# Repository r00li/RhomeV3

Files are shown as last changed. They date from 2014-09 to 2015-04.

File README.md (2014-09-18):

Rhome V3
=========

Rhome V3 is a stand-alone ARM based room automation system. It features:

  - (Wireless) Light control
  - Window blind control
  - Local LCD based GUI
  - Wireless remote control (for now 433MHz remotes only)
  - Wifi connectivity
  - Easy to use web control interface (integrated web server)

It runs on a standard STM32F4 Cortex M4 microcontroller. This project includes all the necessary source code (EMBLOCKS PROJECT folder) and eagle board files with schematics (SCHEMATIC folder). I will also add .stl files for a 3D printed case later.

Changelog
----

0.1:

This is an alpha release and needs a lot of code cleanup. More details on how to set eveything up are comming later.

Requirements
-----------

You will need the following things to get this running:

  - A built and ready Rhome V3 PCB (or an STM32F4 discovery board with necessary components connected)
  - A sailwinch servo for each window blind that you want to control (more details are comming later)
  - A wireless 433MHz switch for each light that you want to control (I am using ones made by Intertechno, but others should work)
  - An STM32F4 Discovery board for programming (anything with STLINK should work though)
  - 5V power supply (computer USB port should work though some have trouble powering the PCB with servo motors attached)
  - A running installation of em::blocks IDE (open source, very easy to use) for compiling and uploading the project to the board

After that you just need is to connect your STLINK programmer to the programming interface on the board, select release in the em::blocks IDE and upload the code to the board. All the configuration is done through the integrated GUI.

License
----

GNU GPL v3 - see LICENSE for more details

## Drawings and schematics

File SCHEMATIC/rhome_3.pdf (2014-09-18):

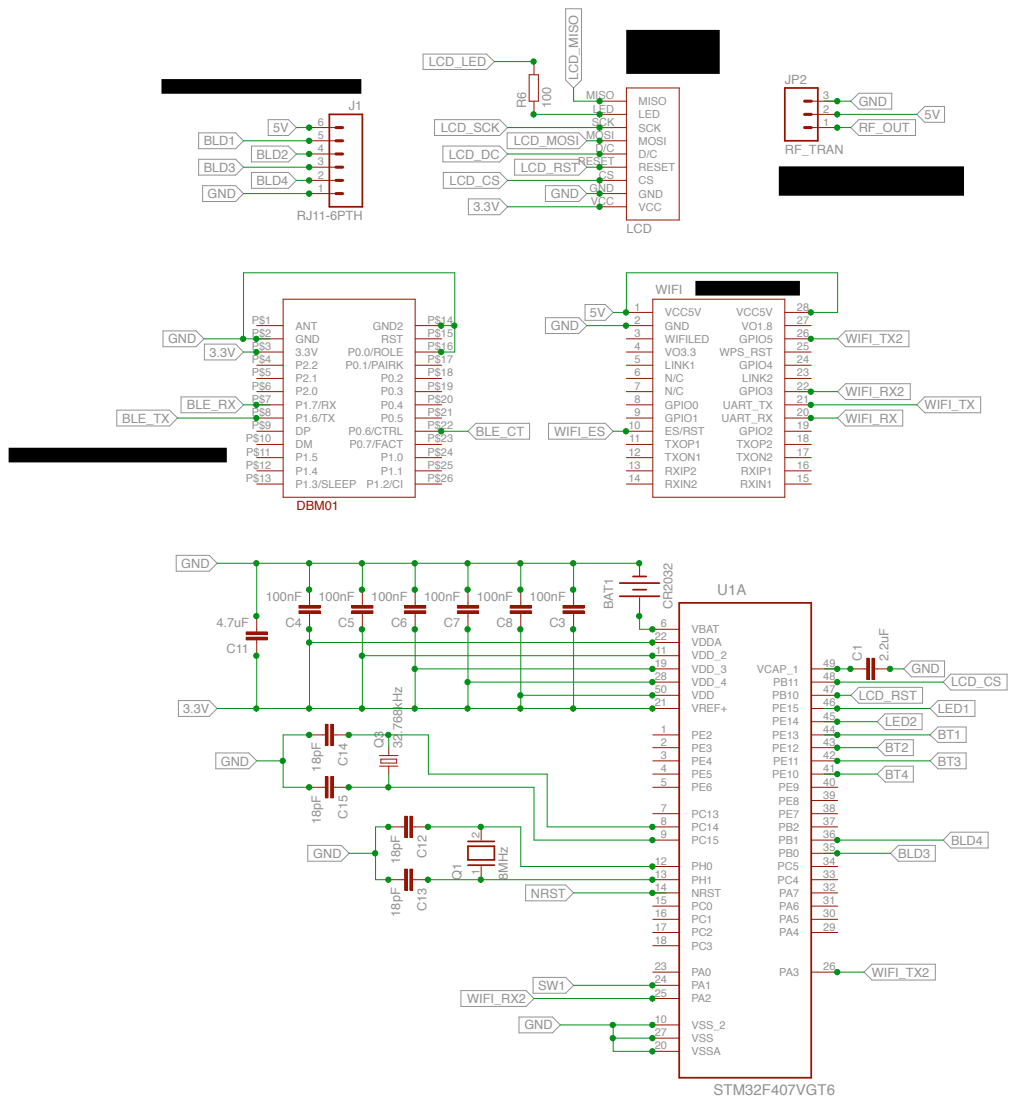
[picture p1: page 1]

VDD_2 11
VDD_3 19
VDD_4 28
VDD 50

# LCD_MISOUSB

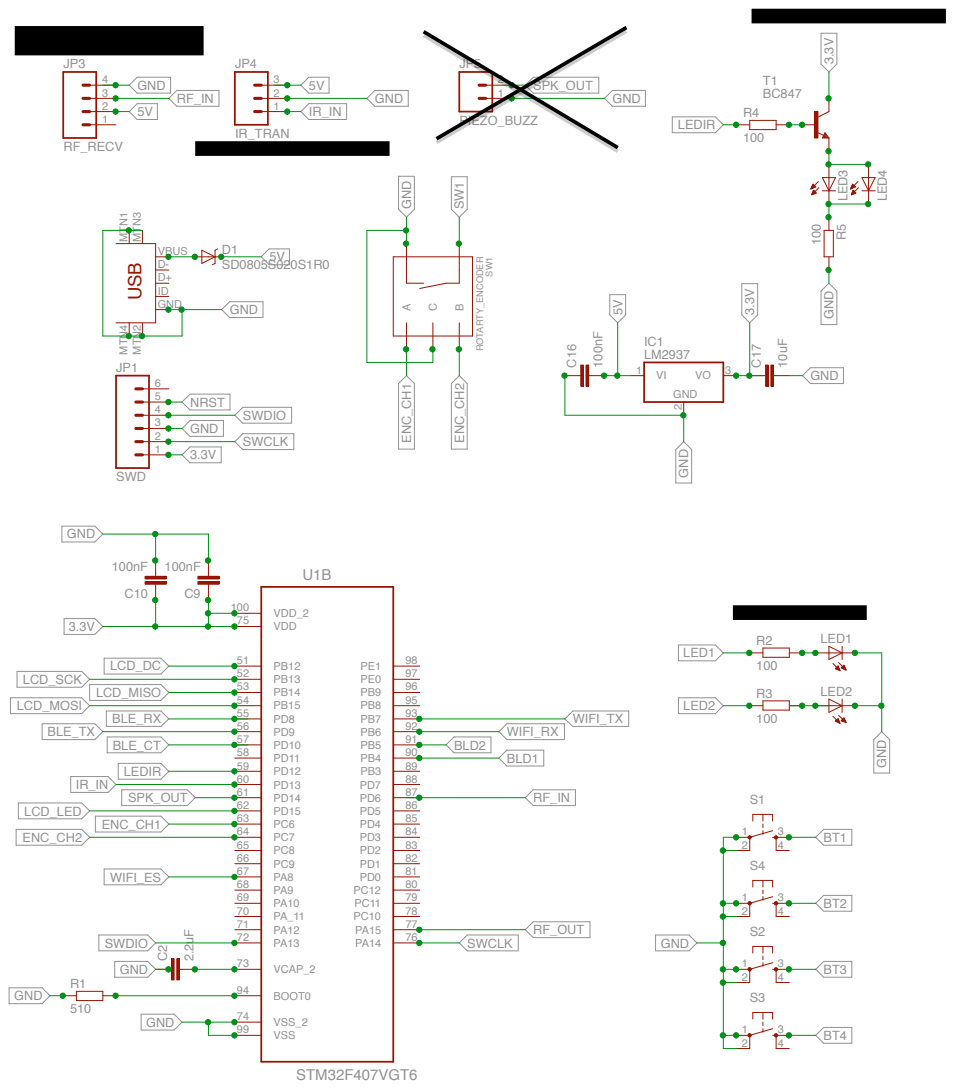
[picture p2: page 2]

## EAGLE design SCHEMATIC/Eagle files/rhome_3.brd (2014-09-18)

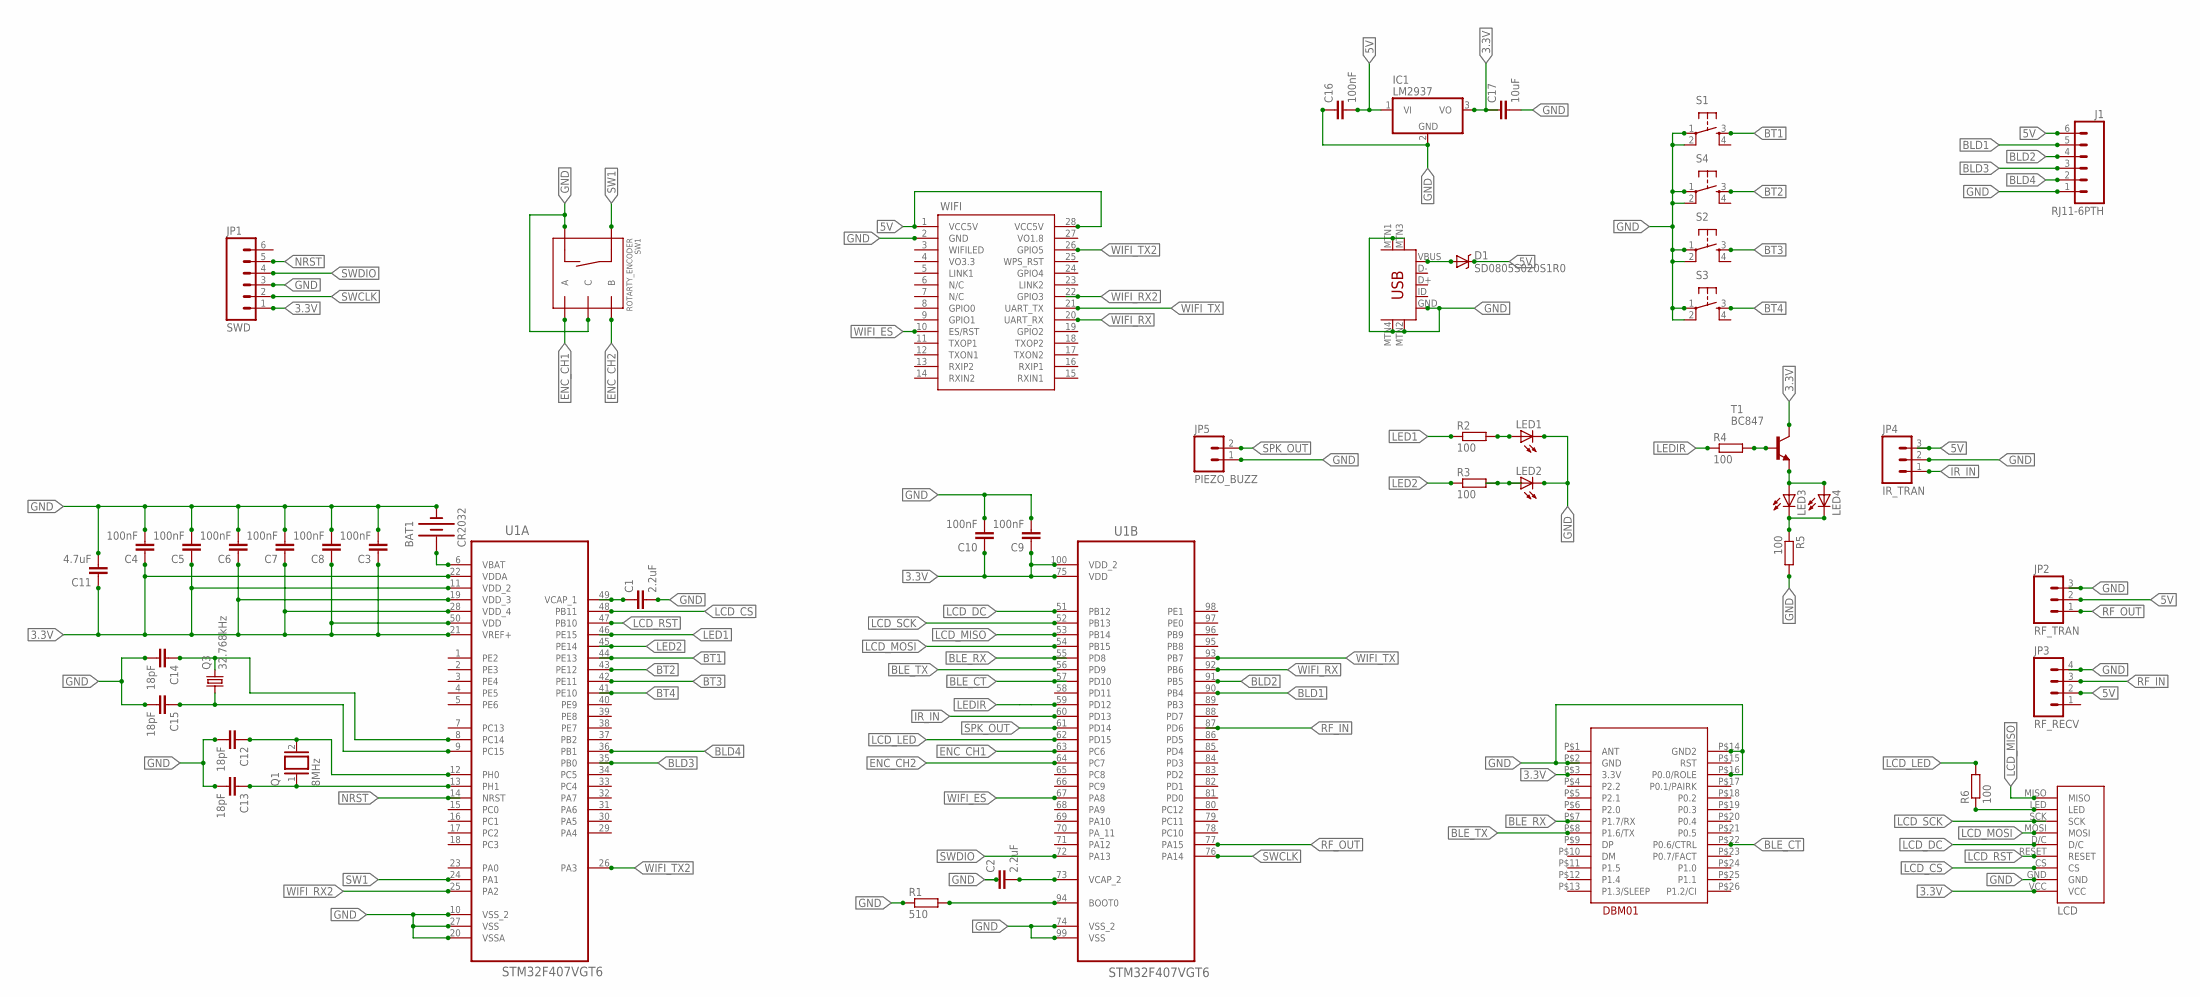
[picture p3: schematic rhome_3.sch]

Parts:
BAT1: CR2032; BATTCON_20MM
C1, C2: 2.2uF; 0805
C3, C4, C5, C6, C7, C8, C9, C10, C16: 100nF; 0805
C11: 4.7uF; 0805
C12, C13, C14, C15: 18pF; 0805
C17: 10uF; 0805
D1: SD0805S020S1R0; SOD-323
DBM01: DBM01; SMD
IC1: LM2937; TO263-3
J1: RJ11-6PTH; RJ11-6
JP1: SWD; 1X06
JP2: RF_TRAN; 1X03
JP3: RF_RECV; 1X04
JP4: IR_TRAN; 1X03
JP5: PIEZO_BUZZ; 1X02_LOCK
LCD: ILI9341_SPI_LCD; LCD
LED1, LED2, LED3, LED4: LED5MM
Q1: 8MHz; QS
Q3: 32.768kHz; MC-306
R1: 510; R0805
R2, R3, R4, R5, R6: 100; R0805
S1, S2, S3, S4: TAC_SWITCHPTH; TACTILE-PTH
SW1: ROTARTY_ENCODER; ROTARY_ENC_PLAIN
T1: BC847; SOT23
U1: STM32F407VGT6; QFP50P1600X1600X160-100N
U$1: USB-MINIB-5PIN; USB-MINIB
WIFI: HLK-RM04

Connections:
3.3V: C3.1, C4.1, C5.1, C6.1, C7.1, C8.1, C9.1, C10.1, C11.1, C17.1, DBM01.P$3 (3.3V), IC1.3 (VO), JP1.1, LCD.VCC, T1.3 (C), U1.11 (VDD_2), U1.19 (VDD_3), U1.21 (VREF+), U1.22 (VDDA), U1.28 (VDD_4), U1.50 (VDD), U1.75 (VDD), U1.100 (VDD_2)
5V: C16.2, D1.1 (C), IC1.1 (VI), J1.6, JP2.2, JP3.2, JP4.3, WIFI.1 (VCC5V), WIFI.28 (VCC5V)
BLD1: J1.5, U1.90 (PB4)
BLD2: J1.4, U1.91 (PB5)
BLD3: J1.3, U1.35 (PB0)
BLD4: J1.2, U1.36 (PB1)
BLE_CT: DBM01.P$22 (P0.6/CTRL), U1.57 (PD10)
BLE_RX: DBM01.P$7 (P1.7/RX), U1.55 (PD8)
BLE_TX: DBM01.P$8 (P1.6/TX), U1.56 (PD9)
BT1: S1.3, U1.44 (PE13)
BT2: S4.3, U1.43 (PE12)
BT3: S2.3, U1.42 (PE11)
BT4: S3.3, U1.41 (PE10)
ENC_CH1: SW1.A, U1.63 (PC6)
ENC_CH2: SW1.B, U1.64 (PC7)
GND: BAT1.2 (-), C1.2, C2.1, C3.2, C4.2, C5.2, C6.2, C7.2, C8.2, C9.2, C10.2, C11.2, C12.2, C13.2, C14.2, C15.2, C16.1, C17.2, DBM01.P$2 (GND), DBM01.P$14 (GND2), DBM01.P$16 (P0.0/ROLE), IC1.2 (GND), J1.1, JP1.3, JP2.3, JP3.4, JP4.2, JP5.1, LCD.GND, LED1.K (C), LED2.K (C), R1.1, R5.2, S1.1, S1.2, S2.1, S2.2, S3.1, S3.2, S4.1, S4.2, SW1.C, SW1.SW-, U1.10 (VSS_2), U1.20 (VSSA), U1.27 (VSS), U1.74 (VSS_2), U1.99 (VSS), U$1.GND, U$1.MTN1 (MTN2), U$1.MTN2 (MTN3), U$1.MTN3 (MTN1), U$1.MTN4, WIFI.2 (GND)
IR_IN: JP4.1, U1.60 (PD13)
LCD_CS: LCD.CS, U1.48 (PB11)
LCD_DC: LCD.D/C, U1.51 (PB12)
LCD_LED: R6.2, U1.62 (PD15)
LCD_MISO: LCD.MISO, U1.53 (PB14)
LCD_MOSI: LCD.MOSI, U1.54 (PB15)
LCD_RST: LCD.RESET, U1.47 (PB10)
LCD_SCK: LCD.SCK, U1.52 (PB13)
LED1: R2.1, U1.46 (PE15)
LED2: R3.1, U1.45 (PE14)
LEDIR: R4.1, U1.59 (PD12)
unnamed: C2.2, U1.73 (VCAP_2)
unnamed: C1.1, U1.49 (VCAP_1)
unnamed: C14.1, Q3.4 (2), U1.8 (PC14)
unnamed: C13.1, Q1.1, U1.13 (PH1)
unnamed: C12.1, Q1.2, U1.12 (PH0)
unnamed: C15.1, Q3.1, U1.9 (PC15)
unnamed: D1.2 (A), U$1.VBUS
unnamed: BAT1.1 (+), U1.6 (VBAT)
unnamed: LED1.A, R2.2
unnamed: LED2.A, R3.2
unnamed: R4.2, T1.1 (B)
unnamed: LED3.A, LED4.A, T1.2 (E)
unnamed: R1.2, U1.94 (BOOT0)
unnamed: LED3.K (C), LED4.K (C), R5.1
unnamed: LCD.LED, R6.1
NRST: JP1.5, U1.14 (NRST)
RF_IN: JP3.3, U1.87 (PD6)
RF_OUT: JP2.1, U1.77 (PA15)
SPK_OUT: JP5.2, U1.61 (PD14)
SW1: SW1.SW+, U1.24 (PA1)
SWCLK: JP1.2, U1.76 (PA14)
SWDIO: JP1.4, U1.72 (PA13)
WIFI_ES: U1.67 (PA8), WIFI.10 (ES/RST)
WIFI_RX: U1.92 (PB6), WIFI.20 (UART_RX)
WIFI_RX2: U1.25 (PA2), WIFI.22 (GPIO3)
WIFI_TX: U1.93 (PB7), WIFI.21 (UART_TX)
WIFI_TX2: U1.26 (PA3), WIFI.26 (GPIO5)

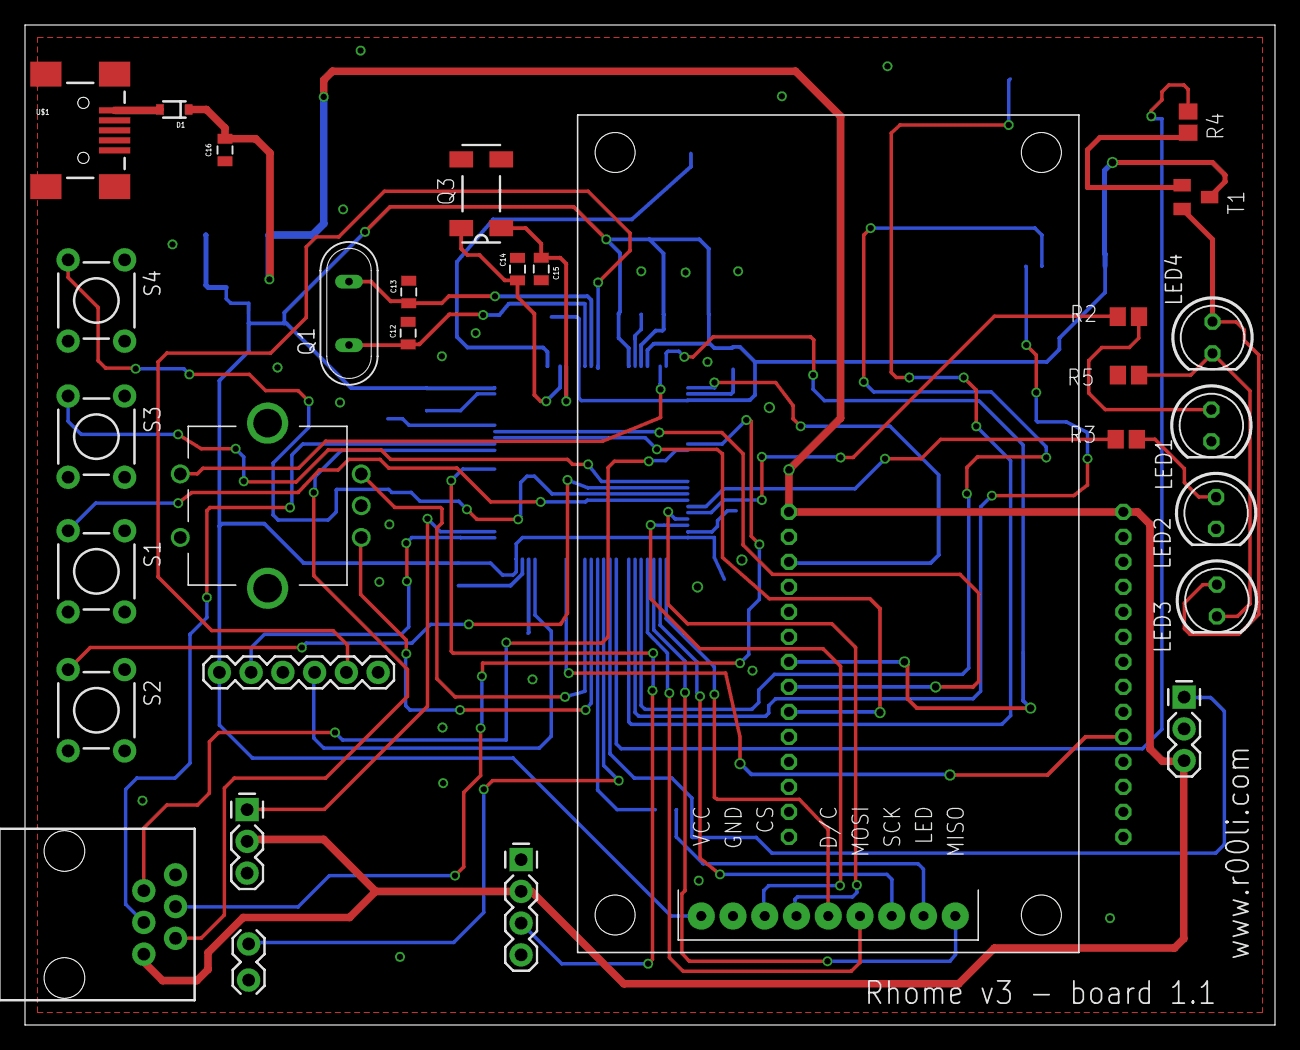
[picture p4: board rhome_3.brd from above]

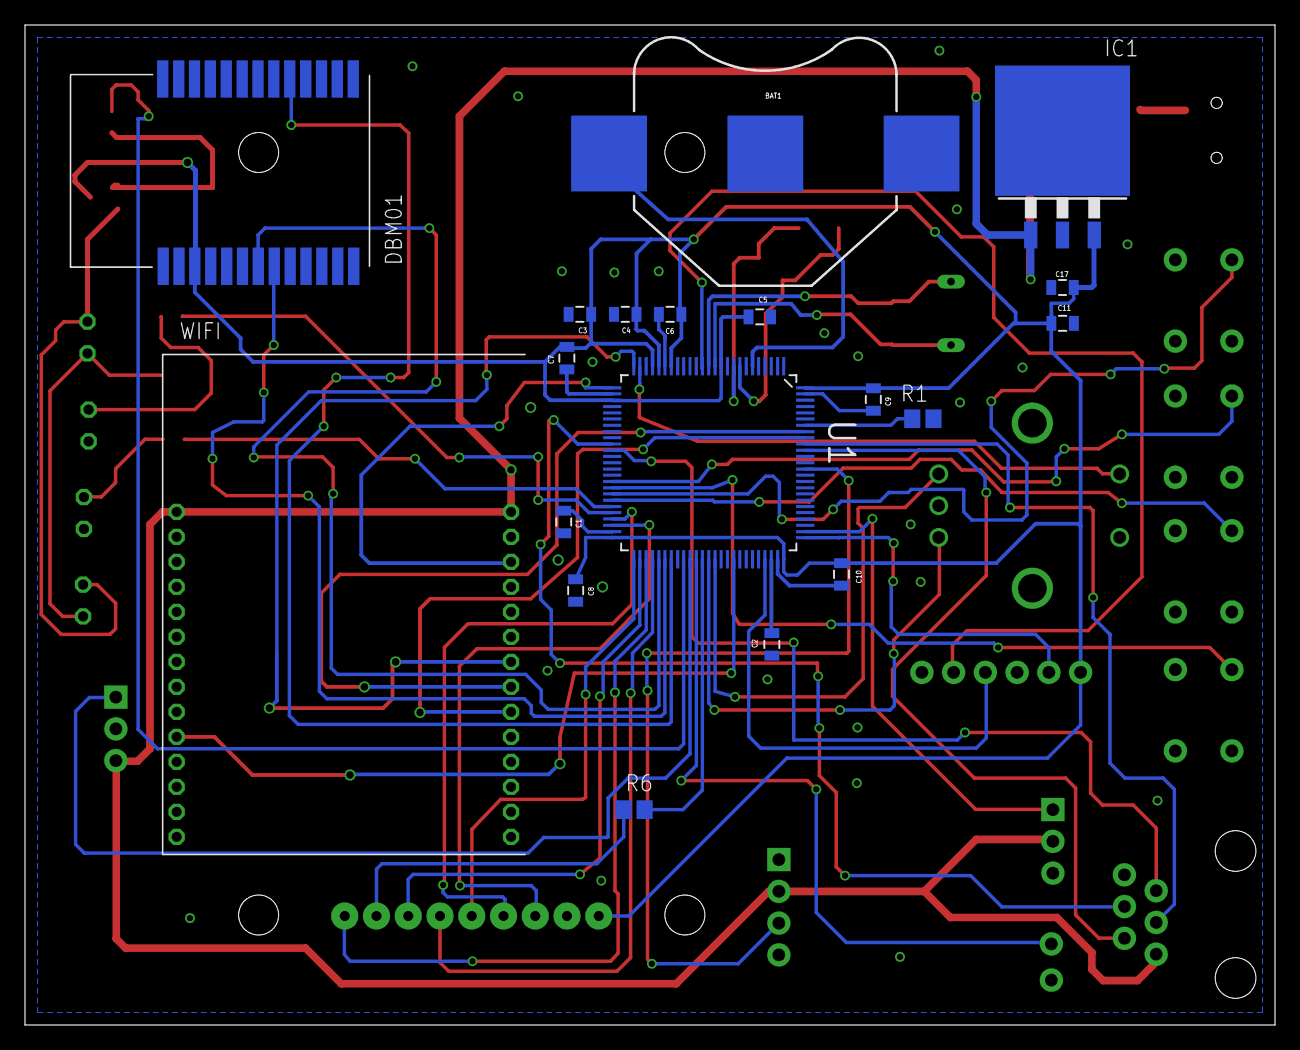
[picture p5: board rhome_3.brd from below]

Board: 2 copper layers, 100.0 x 80.0 mm, 49 parts (19 on the bottom side), 54 nets.

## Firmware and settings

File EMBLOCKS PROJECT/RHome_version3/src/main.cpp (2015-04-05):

/*
**
**                           Main.cpp
**
**
**********************************************************************/
/*
   Author:                 Andrej Rolih
                           www.r00li.com
   Version:                0.1
   License:                GNU GPL v3
                           See attached LICENSE file for details
                           External library files do not include such header and
                           are released under GPL v3 or their specific license.
                           Check those files for more details.

**********************************************************************/

#include "stm32f4xx_conf.h"
#include "stm32f4xx_exti.h"
#include "stm32f4xx_gpio.h"
#include "stm32f4xx_rcc.h"
#include "stm32f4xx_usart.h"
#include "misc.h"
#include "stm32f4xx_syscfg.h"
#include "stm32f4xx_rtc.h"
#include "stm32f4xx_pwr.h"
#include "stm32f4xx_flash.h"


#include "tm_stm32f4_ili9341.h"
#include "tm_stm32f4_fonts.h"

#include "FreeRTOS.h"
#include "task.h"
#include "semphr.h"

#include <stdio.h>
#include <string>
#include <sstream>
#include <stdlib.h>
#include <functional>

#include "Lighting.h"
#include "Menu.h"
#include "Blinds.h"
#include "RemoteTransmitter.h"
#include "RemoteReceiver.h"
#include "TempSensor.h"
#include "Remote.h"

#include "essentials.h"

//
// Redefinition of operators new and delete so that
// dynamic memory allocation can work with Free RTOS
//
void *operator new(size_t size)
{
    void *p;

    if(uxTaskGetNumberOfTasks())
        p=pvPortMalloc(size);
    else
        p=malloc(size);

    return p;
}

void operator delete(void *p)
{
    if(uxTaskGetNumberOfTasks())
        vPortFree( p );
    else
        free( p );

    p = NULL;
}

//
// Functions declarations for some of the functions
//
void Delay(__IO uint32_t nCount);
void vApplicationStackOverflowHook( xTaskHandle pxTask, signed char *pcTaskName );
void vApplicationMallocFailedHook(void);
void vTask1Function (void *pvParameters);
void vTask2Function (void *pvParameters);
void menuCheckerTask(void *pvParameters);
void displayInfoScreen();
void remoteEvent(uint32_t event_code);

//
// Settings for maximum number of automation units
// Also definitions for vectors where we store this data
//
#define kMAX_LIGHTS 5
#define kMAX_BLINDS 4
#define kMAX_BUTTONS 50
std::vector<Light *> lights;
std::vector<Blind *> blinds;
std::vector<RemoteButton *> remoteButtons;

//
// Menu variables (menu stack, currently drawn menu options, ...)
//
std::vector<MenuOption *> mainMenuOptions;
std::vector<std::vector<MenuOption *>> menuStack;
std::vector<MenuOption *> pressedMenuOptionsStack;

//
// Temperature sensing variables
//
InternalTempSensor tempSensor;
uint8_t tempAdjust = 0;

//
// Wifi connection 1 buffer
//
const int eth1_buff_size = 800;
volatile char eth1_buff[eth1_buff_size];
volatile int eth1_buff_indicator = 0;
volatile uint8_t eth1_busy = 0;

//
// Wifi connection 2 buffer
//
const int eth2_buff_size = 400;
volatile char eth2_buff[eth2_buff_size];
volatile int eth2_buff_indicator = 0;
volatile uint8_t eth2_busy = 0;

//
// Ethernet response buffer
//
char eth_send_buff[6000];
volatile unsigned int eth_send_pointer = 0;

//
// Some global buffers for use across the code
//
int globalIntBuffer[10];
char text_buffer[70];
char mini_text_buffer1[35];
char mini_text_buffer2[35];
char mini_text_buffer3[35];

//
// Alphabet definition (for on-screen keyboard)
//
const char alphabet[][2] = {"a","b","c","d","e","f","g","h","i","j","k","l","m","n","o","p","q","r","s","t","u","v","w","x","y","z", " ","A","B","C","D","E","F","G","H","I","J","K","L","M","N","O","P","Q","R","S","T","U","V","W","X","Y","Z", "0", "1", "2", "3", "4", "5", "6", "7", "8", "9", "_", "-", ".", ",", "+", "(", ")"};
#define kALPHABET_SIZE 70

//
// HLK-RM04 Wifi encryption options and their pretty versions
//
const char wifiEncryptionTypes[][11] = {"None", "WEP open", "WEP", "WPA TKIP", "WPA AES", "WPA2 TKIP", "WPA2 AES", "WPA/2 TKIP", "WPA/2 AES"};
const char wifiEcnryptionCommands[][13] = {"none", "wep_open", "wep", "wpa_tkip", "wpa_aes", "wpa2_tkip", "wpa2_aes", "wpawpa2_tkip", "wpawpa2_aes"};
#define kWifiEncryptionTypes 9

//
// Default web server settings
//
char web_user[15] = "user";
char web_pass[15] = "user";
int webPort = 8080;

//
// Variables for blue status LED
//
int blueLedOnTime = 0;
bool blueLedOn = false;

//
// Delayed actions variables
// Automatic blind open/close, delay light-off
//
int delayedActionTime = 0;
bool delayLightOff = false;
bool delayBlindOpen = false;
bool delayBlindClose = false;

//
// Variables for setting the autoblind timer
// (autoblind is disabled by default)
//
uint8_t automaticBlindOpenHour = 0;
uint8_t automaticBlindOpenMinute = 0;
uint8_t automaticBlindCloseHour = 0;
uint8_t automaticBlindCloseMinute = 0;
uint8_t automaticBlindOpenPosition = 0;
uint8_t automaticBlindClosePosition = 0;
bool autoOpenBlindEnabled = false;
bool autoCloseBlindEnabled = false;

//
// Flash definitions
//
const uint8_t flash_data[] __attribute__ ((section(".eeprom"), used)) = {};
uint8_t flash_status;
uint8_t empty_check;


//
// Interrupt handlers
// Using extern "C" because interrupt handlers can't be inside of C++ code
//
extern "C"
{
    void USART1_IRQHandler(void)
    {
        //
        // Wifi connection 1 handler (server)
        //
        if(USART_GetITStatus(USART1, USART_IT_RXNE) != RESET)
        {
            if (eth1_buff_indicator >= eth1_buff_size || eth1_busy)
            {
                return;
            }

            eth1_buff[eth1_buff_indicator] = USART_ReceiveData(USART1);
            eth1_buff_indicator++;
        }
    }

    void USART2_IRQHandler(void)
    {
        //
        // Wifi connection 2 handler (client)
        //
        if(USART_GetITStatus(USART2, USART_IT_RXNE) != RESET)
        {
            if (eth2_buff_indicator >= eth2_buff_size || eth2_busy)
            {
                return;
            }

            eth2_buff[eth2_buff_indicator] = USART_ReceiveData(USART2);
            eth2_buff_indicator++;
        }
    }

    void EXTI1_IRQHandler(void)
    {
        //
        // Rotary encoder integrated button handler
        //
        if (EXTI_GetITStatus(EXTI_Line1))
        {
            Menu::enterPressed = true;
            Menu::lastInteractionTime = millis();
            delay(10);
        }

        EXTI_ClearITPendingBit(EXTI_Line1);
    }

    void EXTI9_5_IRQHandler(void)
    {
        //
        // RF-receiver handler
        //
        if (EXTI_GetITStatus(EXTI_Line6) != RESET)
        {
            taskENTER_CRITICAL();
            //taskDISABLE_INTERRUPTS();
            RemoteReceiver::interruptHandler();
            EXTI_ClearITPendingBit(EXTI_Line6);
            taskEXIT_CRITICAL();
            //taskENABLE_INTERRUPTS();
        }
    }

    void EXTI15_10_IRQHandler(void)
    {
        //
        // User buttons handler
        //
        if (EXTI_GetITStatus(EXTI_Line13) != RESET)
        {
            remoteEvent(1);
            EXTI_ClearITPendingBit(EXTI_Line13);
        }

        if (EXTI_GetITStatus(EXTI_Line12) != RESET)
        {
            remoteEvent(2);
            EXTI_ClearITPendingBit(EXTI_Line12);
        }

        if (EXTI_GetITStatus(EXTI_Line11) != RESET)
        {
            remoteEvent(3);
            EXTI_ClearITPendingBit(EXTI_Line11);
        }

        if (EXTI_GetITStatus(EXTI_Line10) != RESET)
        {
            remoteEvent(4);
            EXTI_ClearITPendingBit(EXTI_Line10);
        }
    }

    void RTC_Alarm_IRQHandler()
    {
        //
        // RTC alarm handler
        // Used for autoblind
        //
        if(RTC_GetITStatus(RTC_IT_ALRA) != RESET)
        {
            if (autoOpenBlindEnabled)
                delayBlindOpen = true;
            RTC_ClearITPendingBit(RTC_IT_ALRA);
            EXTI_ClearITPendingBit(EXTI_Line17);
        }

        if(RTC_GetITStatus(RTC_IT_ALRB) != RESET)
        {
            if (autoCloseBlindEnabled)
                delayBlindClose = true;
            RTC_ClearITPendingBit(RTC_IT_ALRB);
            EXTI_ClearITPendingBit(EXTI_Line17);
        }
    }

    void HardFault_Handler()
    {
        NVIC_SystemReset();
    }
}


// ------------------------------------------------------------------------------------------------------------------------------------------------------
// FLASH FUNCTIONS
// ------------------------------------------------------------------------------------------------------------------------------------------------------

void loadFromFlash()
{
    //
    // Function loads settings from internal flash
    //

    if (flash_data[0])
    {
        empty_check = 1;
        return;
    }
    else
    {
        uint8_t* address = (uint8_t *) &flash_data[0];
        address += 4;

        //restore lights
        for (int i = 0 ; i < kMAX_LIGHTS; i++)
        {
            unsigned char *data1 = address;
            address += 4;

            uint8_t light_present = data1[0];
            uint8_t light_type = data1[1];
            uint8_t device = data1[3];

            char name[12];
            for (int j=0; j < 12; j++)
            {
                name[j] = *address;
                address++;
            }
            name[11] = '\0';

            uint32_t bt_code = *((uint32_t *)address);
            address += 4;

            uint32_t system_code = *((uint32_t *)address);
            address += 4;

            //additional unused bits
            address += 8;

            if (light_present == 0)
            {
                Light *lght = new Light;
                lght->setName(name);
                lght->btCode = bt_code;

                if (light_type == RF_KAKU)
                    lght->setTypeKaku(device, (unsigned short) system_code);

                lght->onOff(false);

                lights.push_back(lght);
            }
        }

        //restore blinds
        for (int i = 0 ; i < kMAX_BLINDS; i++)
        {
            unsigned char *data1 = address;
            address += 4;

            uint8_t blind_present = data1[0];
            uint8_t blind_channel = data1[1];
            uint8_t blind_type = data1[2];
            //uint8_t device = data1[3];

            uint32_t bt_code = *((uint32_t *)address);
            address += 4;

            uint32_t min_pos = *((uint32_t *)address);
            address += 4;

            uint32_t mid_pos = *((uint32_t *)address);
            address += 4;

            uint32_t max_pos = *((uint32_t *)address);
            address += 4;

            uint32_t step = *((uint32_t *)address);
            address += 4;

            char name[12];
            for (int j=0; j < 12; j++)
            {
                name[j] = *address;
                address++;
            }
            name[11] = '\0';

            //additional unused bits
            address += 8;

            if (blind_present == 0)
            {
                Blind *bld = new Blind;
                bld->setName(name);
                bld->btCode = bt_code;
                bld->setBounds(min_pos, mid_pos, max_pos);
                bld->step = step;
                bld->setType((BlindType) blind_type);
                bld->setChannel((BlindChannel) blind_channel);

                bld->enableOutput(true);
                bld->setPosition(mid_pos);
                delay(1000);
                bld->enableOutput(false);

                blinds.push_back(bld);
            }
        }

        //restore remote/buttons
        for (int i = 0 ; i < kMAX_BUTTONS; i++)
        {
            unsigned char *data1 = address;
            address += 4;

            uint8_t button_present = data1[0];
            uint8_t event_type = data1[1];

            uint32_t buttonCode = *((uint32_t *)address);
            address += 4;

            uint32_t eventHash = *((uint32_t *)address);
            address += 4;

            if (button_present == 0)
            {
                RemoteButton* btn = new RemoteButton();
                btn->eventHash = eventHash;
                btn->remoteButton = buttonCode;
                btn->eventType = (RemoteEventType) event_type;

                remoteButtons.push_back(btn);
            }
        }

        //restore web server settings
        {
            unsigned char *data1 = address;
            address += 4;

            uint8_t settingsSaved = data1[0];

            uint32_t port = *((uint32_t *)address);
            address += 4;

            char user[16];
            for (int j=0; j < 16; j++)
            {
                user[j] = *address;
                address++;
            }
            user[14] = '\0';

            char pass[16];
            for (int j=0; j < 16; j++)
            {
                pass[j] = *address;
                address++;
            }
            pass[14] = '\0';

            if (settingsSaved == 0)
            {
                webPort = port;
                strncpy(web_user, user, 15);
                strncpy(web_pass, pass, 15);
            }
        }

        //restore auto blind settings
        {
            unsigned char *data1 = address;
            address += 4;

            autoOpenBlindEnabled = data1[0];
            automaticBlindOpenHour = data1[1];
            automaticBlindOpenMinute = data1[2];
            automaticBlindOpenPosition = data1[3];

            unsigned char *data2 = address;
            address += 4;

            autoCloseBlindEnabled = data2[0];
            automaticBlindCloseHour = data2[1];
            automaticBlindCloseMinute = data2[2];
            automaticBlindClosePosition = data2[3];
        }

        //restore temp adjustment factor
        {
            unsigned char *data1 = address;
            address += 4;

            if (data1[0] == 0)
            {
                tempAdjust = data1[1];
            }
        }
    }
}
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
int main(void)
{
    //
    // Main function
    // Handles basic setup and initialization
    //

    init_essentials_time();
    GPIO_LED_init();

    TM_ILI9341_Init();
    TM_ILI9341_Rotate(TM_ILI9341_Orientation_Landscape_1);

    TM_ILI9341_Puts(10, 10, "Starting...", &TM_Font_11x18, ILI9341_COLOR_BLACK, ILI9341_COLOR_WHITE);

    LCD_backlight_init();

    initRTC();

    //menuStack.reserve(3);
    //mainMenuOptions.reserve(12);
    //pressedMenuOptionsStack.reserve(6);

    blinds.reserve(4);
    lights.reserve(5);
    remoteButtons.reserve(50);

    loadFromFlash();

    setAutoBlinds();

    RemoteButton::shouldRunActions = true;

    RemoteReceiver::init(0,remoteEventRF);

    Blind::initLocalBlinds();

    Menu::initInputMethod();

    tempSensor.initTempSensor();
    tempSensor.calibration = tempAdjust;

    Menu::clearMenu();
    Menu::clearTitle();
    Menu::clearRightMenu();

    MenuOption* op1 = new MenuOption(13, 15, "Info", ILI9341_COLOR_WHITE, ILI9341_COLOR_BLACK);
    op1->setOnClickListener(displayInfoScreen);
    op1->setSelected(true);
    op1->doOnClick();

    MenuOption* op2 = new MenuOption(30, 45, "Lights", ILI9341_COLOR_WHITE, ILI9341_COLOR_BLACK);
    op2->setOnClickListener(displayLightMenu);

    MenuOption* op3 = new MenuOption(38, 75, "Blinds", ILI9341_COLOR_WHITE, ILI9341_COLOR_BLACK);
    op3->setOnClickListener(displayBlindMenu);

    MenuOption* op4 = new MenuOption(42, 105, "Actions", ILI9341_COLOR_WHITE, ILI9341_COLOR_BLACK);
    op4->setOnClickListener(displayActionMenu);

    MenuOption* op5 = new MenuOption(38, 135, "Settings", ILI9341_COLOR_WHITE, ILI9341_COLOR_BLACK);
    op5->setOnClickListener(displaySettingsMenu);

    mainMenuOptions.push_back(op1);
    mainMenuOptions.push_back(op2);
    mainMenuOptions.push_back(op3);
    mainMenuOptions.push_back(op4);
    mainMenuOptions.push_back(op5);

    initWifiES();
    init_USART1();
    init_USART2();


    //
    // Create all Free RTOS tasks
    //
    xTaskCreate(
        vTask1Function,                   /*Pinter to the function that implements task*/
        ( const signed char * ) "Task1",  /* Task name - for debugging only*/
        200,         /* Stack depth in words */
        ( void* ) NULL,                   /* Pointer to tasks arguments (parameter) */
        tskIDLE_PRIORITY + 1UL,           /* Task priority*/
        NULL                              /* Task handle */
    );

    xTaskCreate(
        vTask2Function,                   /* Pointer to the function that implements task*/
        ( const signed char * ) "Task2",  /* Task name - for debugging only*/
        200,         /* Stack depth in words */
        ( void* ) NULL,                   /* Pointer to tasks arguments (parameter) */
        tskIDLE_PRIORITY + 1UL,           /* Task priority*/
        NULL                              /* Task handle */
    );

    xTaskCreate(
        task3,                   /* Pointer to the function that implements task*/
        ( const signed char * ) "Task3",  /* Task name - for debugging only*/
        200,         /* Stack depth in words */
        ( void* ) NULL,                   /* Pointer to tasks arguments (parameter) */
        tskIDLE_PRIORITY + 1UL,           /* Task priority*/
        NULL                              /* Task handle */
    );

    xTaskCreate(
        menuCheckerTask,                   /* Pointer to the function that implements task*/
        ( const signed char * ) "Task4",  /* Task name - for debugging only*/
        600,         /* Stack depth in words */
        ( void* ) NULL,                   /* Pointer to tasks arguments (parameter) */
        tskIDLE_PRIORITY + 1UL,           /* Task priority*/
        NULL                              /* Task handle */
    );

    // Start task scheduler
    vTaskStartScheduler();

    while(1)
    {
    }
}

/**
  * @brief  Delay Function.
  * @param  nCount:specifies the Delay time length.
  * @retval None
  */
void Delay(__IO uint32_t nCount)
{
    while(nCount--)
    {
    }
}

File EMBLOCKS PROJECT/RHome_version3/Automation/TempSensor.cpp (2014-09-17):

/*
**
**                           TempSensor.cpp
**
**
**********************************************************************/
/*
   Author:                 Andrej Rolih
                           www.r00li.com
   Version:                0.1
   License:                GNU GPL v3
                           See attached LICENSE file for details
                           External library files do not include such header and
                           are released under GPL v3 or their specific license.
                           Check those files for more details.

**********************************************************************/

#include "TempSensor.h"

#include "FreeRTOS.h"
#include "task.h"

void InternalTempSensor::initTempSensor()
{
    temp = 0;
    calibration = 0;

    ADC_DeInit();

    ADC_InitTypeDef ADC_InitStruct;
    ADC_CommonInitTypeDef ADC_CommonInitStruct;

    RCC_APB2PeriphClockCmd(RCC_APB2Periph_ADC1, ENABLE);

    ADC_CommonInitStruct.ADC_Mode = ADC_Mode_Independent;
    ADC_CommonInitStruct.ADC_Prescaler = ADC_Prescaler_Div8;
    ADC_CommonInitStruct.ADC_DMAAccessMode = ADC_DMAAccessMode_Disabled;
    ADC_CommonInitStruct.ADC_TwoSamplingDelay = ADC_TwoSamplingDelay_5Cycles;
    ADC_CommonInit(&ADC_CommonInitStruct);

    ADC_InitStruct.ADC_Resolution = ADC_Resolution_12b;
    ADC_InitStruct.ADC_ScanConvMode = DISABLE;
    ADC_InitStruct.ADC_ContinuousConvMode = ENABLE;
    ADC_InitStruct.ADC_ExternalTrigConvEdge = ADC_ExternalTrigConvEdge_None;
    ADC_InitStruct.ADC_ExternalTrigConv = ADC_ExternalTrigConv_T1_CC1;
    ADC_InitStruct.ADC_DataAlign = ADC_DataAlign_Right;
    ADC_InitStruct.ADC_NbrOfConversion = 1;
    ADC_Init(ADC1, &ADC_InitStruct);

    ADC_RegularChannelConfig(ADC1, ADC_Channel_TempSensor, 1, ADC_SampleTime_144Cycles);
    ADC_TempSensorVrefintCmd(ENABLE);
    ADC_Cmd(ADC1, ENABLE);
}

void InternalTempSensor::measureTemp(bool calibrate)
{
    // ADC Conversion to read temperature sensor
    // Temperature (in °C) = ((Vsense – V25) / Avg_Slope) + 25
    // Vense = Voltage Reading From Temperature Sensor
    // V25 = Voltage at 25°C, for STM32F407 = 0.76V
    // Avg_Slope = 2.5mV/°C
    // This data can be found in the STM32F407VF Data Sheet


    taskENTER_CRITICAL();
    ADC_SoftwareStartConv(ADC1); //Start the conversion
    while (ADC_GetFlagStatus(ADC1, ADC_FLAG_EOC) == RESET) {} ; //Processing the conversion

    temp = ADC_GetConversionValue(ADC1); //Return the converted data
    temp *= 3300;
    temp /= 0xfff; //Reading in mV
    temp /= 1000.0; //Reading in Volts
    temp -= 0.760; // Subtract the reference voltage at 25°C
    temp /= .0025; // Divide by slope 2.5mV
    temp += 25.0; // Add the 25°C

    if (calibrate)
    {
        temp -= calibration;
    }

    taskEXIT_CRITICAL();
}

float InternalTempSensor::getTemp(bool calibrate)
{
    measureTemp(calibrate);
    float t1 = temp;
    measureTemp(calibrate);
    float t2 = temp;
    measureTemp(calibrate);
    float t3 = temp;
    measureTemp(calibrate);
    float t4 = temp;

    temp = (t1+t2+t3+t4)/4.0;

    return temp;
}

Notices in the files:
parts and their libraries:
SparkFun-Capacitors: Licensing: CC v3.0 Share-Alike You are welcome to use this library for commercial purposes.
